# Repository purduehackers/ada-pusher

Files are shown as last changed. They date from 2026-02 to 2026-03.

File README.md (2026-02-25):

# ada-pusher

Companion to [door-opener][door-opener-github] to push the Bechtel ADA button

[door-opener-github]: https://github.com/purduehackers/door-opener

## Links

- [Documentation](./docs/README.md)

## Build

You need to install the [Rust on ESP32][esp32-rs-start] prerequisites. These
commands may be useful:

```
cargo binstall espup
espup install
. ~/export-esp.sh
cargo binstall espflash
cargo binstall ldproxy
```

Create a `.env` file with the following contents:

```
PAIRING_PIN=123456
```

This is the pairing PIN used by `ada-pusher`. Replace with a suitable 6-digit PIN.

Then, build with `cargo build`.

Connect the ESP32 board to your computer and run:

```
espflash flash --monitor target/xtensa-esp32-espidf/debug/ada-pusher
```

[esp32-rs-start]: https://docs.espressif.com/projects/rust/book/getting-started/index.html

## Troubleshooting

### Max path on Windows

On Windows, you may encounter the following error:

```
error: failed to run custom build command for `esp-idf-sys v0.36.1`

Caused by:
  process didn't exit successfully: `C:\Users\user\Projects\ada-pusher\target\debug\build\esp-idf-sys-585097b028c03f00\build-script-build` (exit code: 1)
  --- stderr
  Error: Too long output directory: `\\?\C:\Users\user\Projects\ada-pusher\target\xtensa-esp32-espidf\debug\build\esp-idf-sys-7336b0b778f8f8a0\out`. Shorten your project path down to no more than 10 characters (or use WSL2 and its native Linux filesystem). Note that tricks like Windows `subst` do NOT work!
warning: build failed, waiting for other jobs to finish...
```

This is because you need to explicitly opt in to long file paths on Windows.
Recent versions of Windows enable long paths by default, but you need to let
ESP-IDF know of this. Set the environment variable:

```
$env:ESP_IDF_PATH_ISSUES = "warn"
```

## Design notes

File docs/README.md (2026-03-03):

# Documentation

Welcome to the `ada-pusher` documentation.

## BOM

| Name | URL | Notes |
|---|-----|---|
| ESP32 | The cheapest one you can find | `ESP32-WROOM-32D`, see notes below |
| L298N | [Amazon](https://www.amazon.com/dp/B0C5JCF5RS) | Motor driver/controller for linear actuator |
| LM2596 | [Amazon](https://www.amazon.com/dp/B0DBVYP91F) | Buck converter (15V -> 12V), suitable for motors and high power applications |
| Mini360 | [Amazon](https://www.amazon.com/dp/B08HQDSQZP) | Buck converter (15V -> 5V), suitable for low power applications such as the ESP32 board |
| USB-C PD Trigger Board | [Amazon](https://www.amazon.com/dp/B0CFTXRHLV) | Any trigger board should work, just make sure it supports 15V profile at minimum! |
| Suction cups | [Amazon](https://www.amazon.com/dp/B0DFLZ5FX4) | Other suction cups may need calibration, see notes below |
| 100 nF (0.1 uF) capacitor | | |

### Notes

- For the ESP32, if replacing, try to get one with the RISC-V architecture
  - Implementation `v1` uses `ESP32-WROOM-32D`, which is based on Xtensa, and while it works, there are some annoyances where you have to install a modified toolchain and LLVM compiler from Espressif.
  - Only get Xtensa-based boards if they are significantly cheaper than the RISC-V-based ones.
  - If you are working on `v2`+ and we have switched over to RISC-V-based ESP32 boards, please update this documentation and the main `README.md` of this repository and remove the custom toolchain/LLVM installation mention.
  - WARNING: different ESP32 boards may have different pinouts. If you have replaced the boards, do NOT put them on the pre-existing perfboard without verifying the pinout or you may fry your ESP32 board!
- For suction cups:
  - The Purdue Hackers office will stock replacements, should the existing suction cups on `ada-pusher` wear out. Please ask an organizer/officer if you notice the suction cups need replacing.
  - If the particular suction cups listed in the BOM become unavailable, you may source replacements if the nub portion of the suction cup is around 14.5mm in diameter.
  - If the particular suction cups listed in the BOM become unavailable, **and** the replacements have a different nub dimension:
    - Measure the nub diameter with a caliper.
    - Print out the `suction-cup-hole-calibration.FCStd` file in `../cad/` in this repository. You may need to export the model as a `.step` file.
    - Fit the new suction cup into the calibration and determine the correct hole diameter.
    - Open the `ada-pusher.FCStd` project file in `../cad/` in this repository. Open the spreadsheet.
    - Find the `Suction cup inner nub diameter` entry and change the value next to it. Wait while FreeCAD recalculates the model.
    - Export the new model as a `.step` file.
    - Print out the new model and verify fit.
    - Commit and push the new model to this repository (or make a pull request).

## Circuit

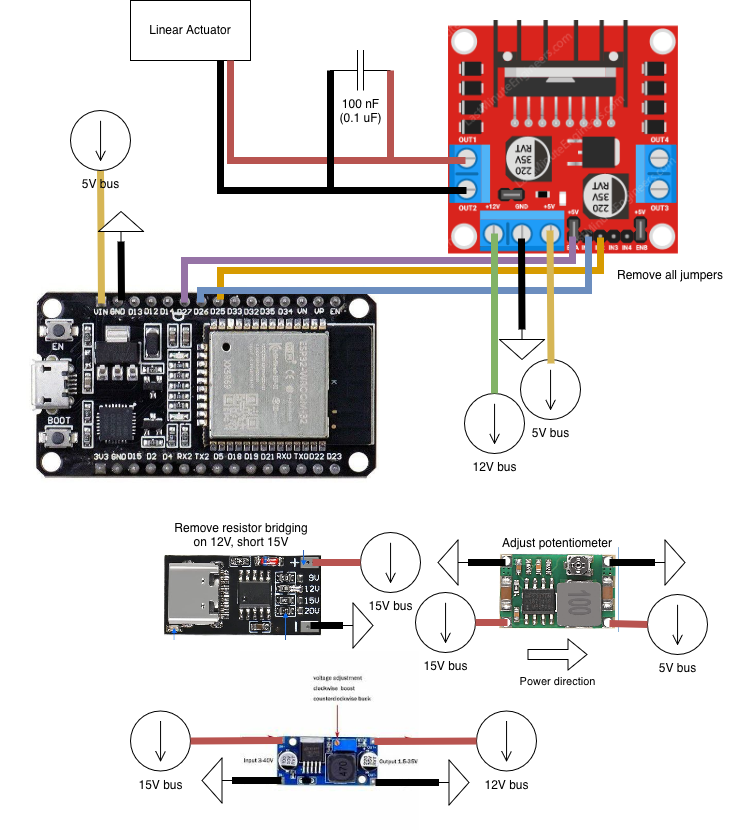
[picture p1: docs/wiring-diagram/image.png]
Circuit diagram


- For the `L298N` driver:
  - Make sure to remove all jumpers. This includes the `ENA` and `ENB` pins, and the voltage regulator jumper (above the 12V and `GND` terminals)! This is because we supply our own 5V, and having it conflict with the 5V voltage regulator of the `L298N` driver board would be problematic!
  - Solder a 100 nF (0.1 uF) capacitor across the output pins (the pins that connect to the linear actuator)
- Adjust the potentiometer on the Mini360 until the output voltage is 5V when input is 15V.
- Adjust the potentiometer on the LM2596 until the output voltage is 12V when input is 15V.
- For the USB-C trigger board:
  - Most USB-C chargers/power adapters do not support the 12V profile, since the USB specification has deemed it optional. Therefore, we get 15V and drop it down to the required voltages, which is probably preferred as the power is more stable overall.
  - The particular board from Amazon comes with a tiny resistor between the 12V profile resistor and ground. You **must** remove this resistor, or else you may get a 9V output.
  - Solder the 15V profile resistor and the ground pad next to it together.
  - Verify 15V output when connected to a capable 15V USB-C PD source with a multimeter.
  - **Warning**: connecting a low-power USB-C PD source or a non-PD USB-C power source will result in the voltage dropping down to the highest voltage that the PD source can supply, which will usually be 5V or 9V. `ada-pusher` will not work with those voltages.
- For the Mini360:
  - The used chip (at least the one from Amazon) is the `MP1482DS`, and the [datasheet can be found here](https://www.monolithicpower.com/en/documentview/productdocument/index/version/2/document_type/Datasheet/lang/en/sku/MP1482/)
    - Funnily enough, the datasheet has a watermark saying the use is discouraged and to move over to the `MP1476`. Perhaps I have received old stock?
  - It may be worth removing the fiddly potentiometer and replacing it with a resistor.
    - The datasheet says Vout is determined by Vout = 0.923 * (R1 + R2) / R2
    - On the Mini360 board, R2 appears to be 8.2k Ohms (from the `822` marking on the resistor)
    - Thus, for Vout = 5V, R1 must be R1 = 5V * 8.2k Ohms / 0.923 - 8.2k Ohms = 36.2k Ohms
    - With testing (theory only goes so far), needed 36.9k Ohms total in order to get stable 5V. Wired 3.9k and 33k Ohm resistors in series:
      Mini360 after resistors are soldered
    - Note: You could also solder between the left pad and the middle pad, not squeeze into the left top and bottom. I did so because I ripped the middle pad off while clipping off the original potentiometer.
    - Wrap with Kapton tape to prevent shorting before assembly.
- For the LM2596:
  - Same thing as Mini360 where we replace the potentiometer with a resistor:
    - According to [the datasheet](https://www.ti.com/lit/ds/symlink/lm2596.pdf), Vout = 1.23 (1 + R2 / R1)
    - On the board, a trimpot ([3296 datasheet](https://www.bourns.com/pdfs/3296.pdf)) provides both R1 and R2.
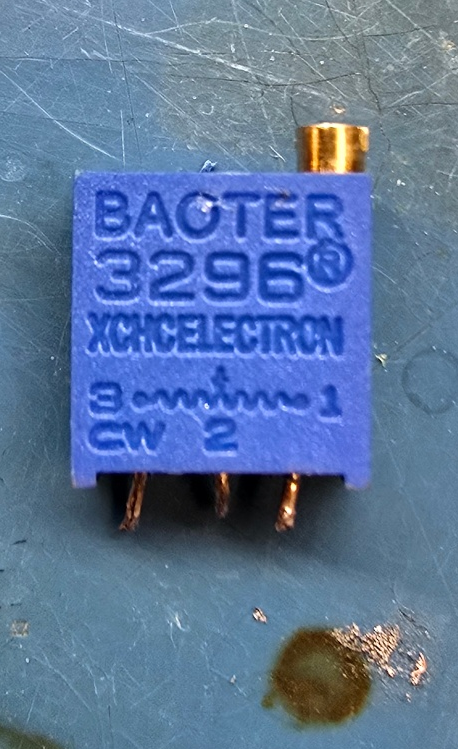
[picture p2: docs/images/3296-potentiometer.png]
3296 potentiometer
      
    - After setting the trimpot to output 12V and desoldering it, the measurements are as follows:
      - Between pins 1 and 2: 2.38k Ohms
      - Between pins 2 and 3: 7.48k Ohms
      - Between pins 1 and 3 (total): 9.8k Ohms
    - Solder resistors such that both legs are in the center pin, and the other legs of the resistors go to each pin hole on either side. In the image, the right resistor is 2.4k Ohms, and the left resistor is 7.5k Ohms.
      LM2596 after resistors are soldered

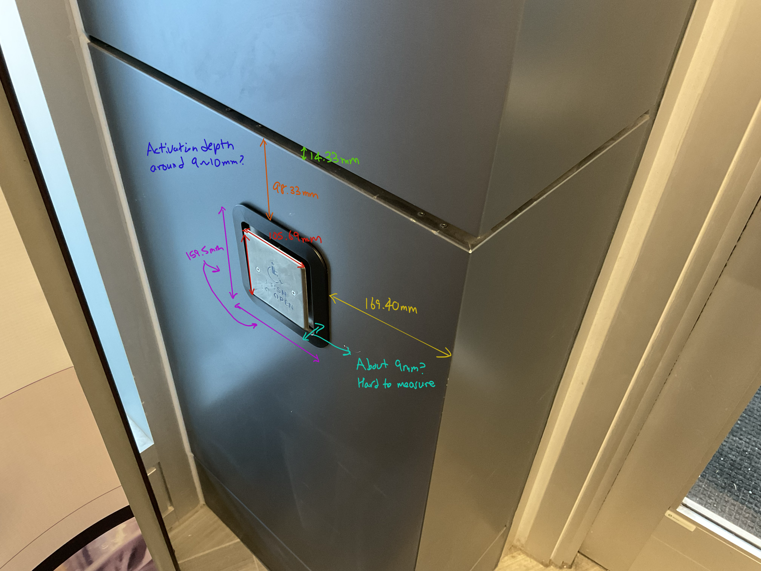
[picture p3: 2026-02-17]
cad/references/reference.png

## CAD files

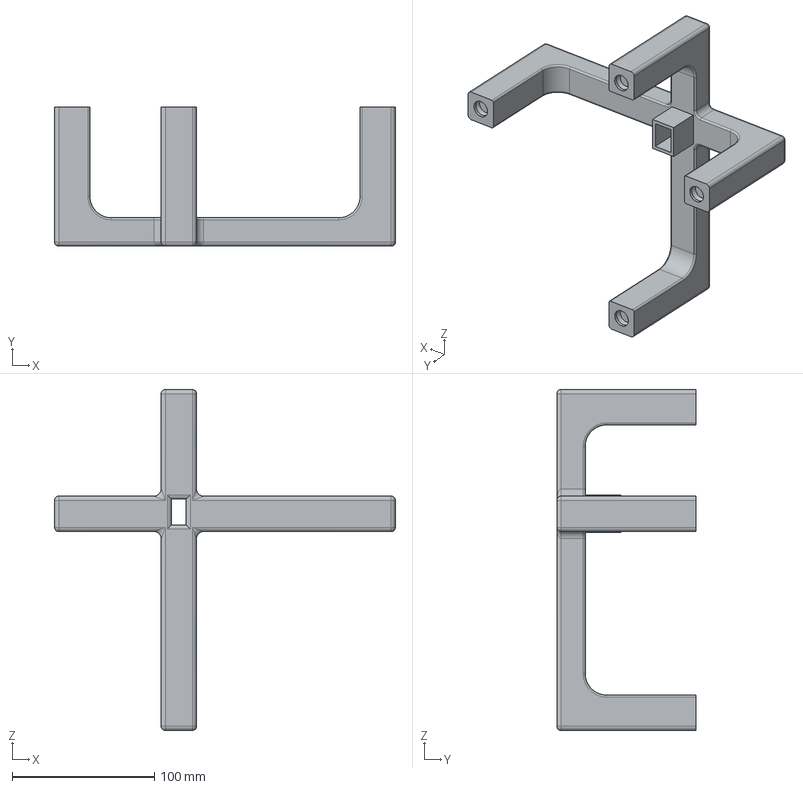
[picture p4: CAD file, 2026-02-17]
cad/parts/ada-pusher_v7.step
240.0 x 98.0 x 240.0 mm

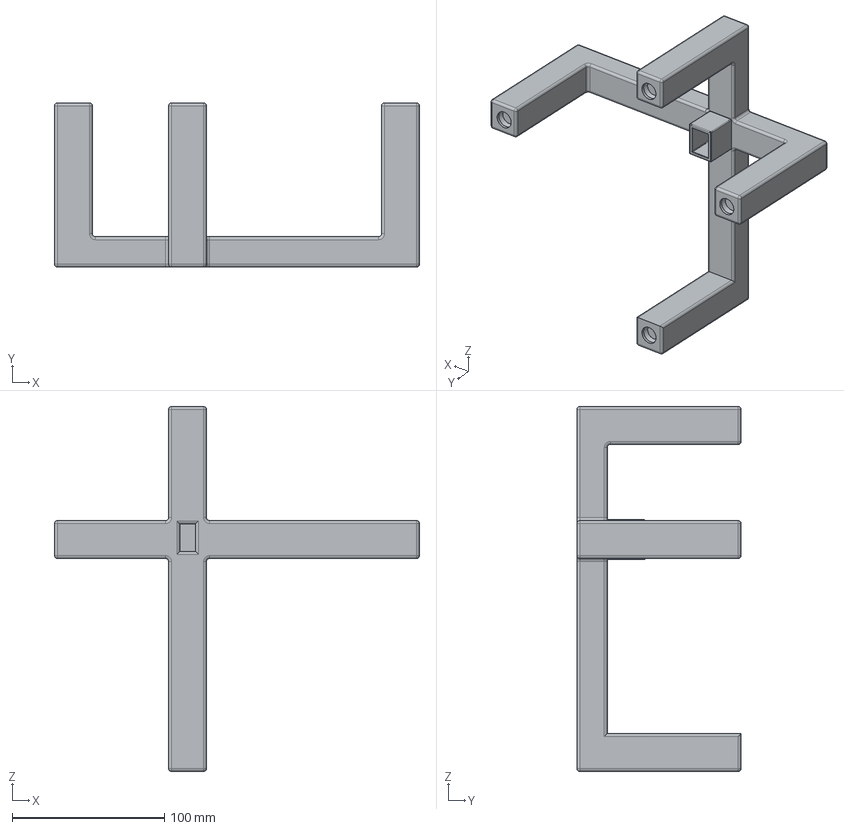
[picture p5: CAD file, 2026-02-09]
cad/ada-pusher-cad_v4.step
240.0 x 108.0 x 240.0 mm

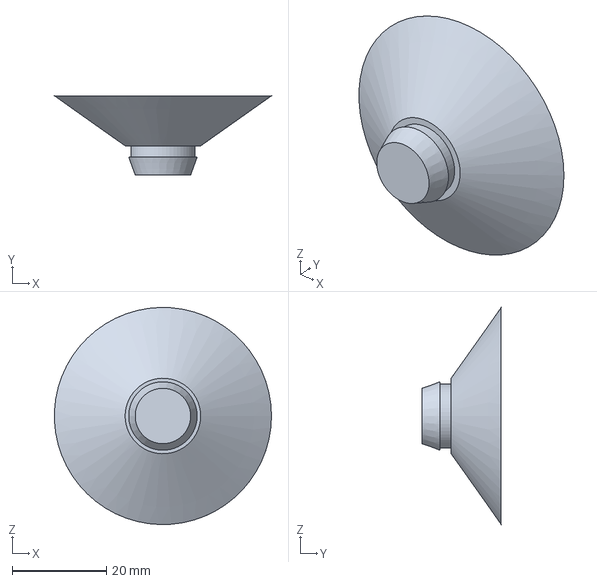
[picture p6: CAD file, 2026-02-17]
cad/parts/suction-cup.FCStd
46.0 x 16.8 x 46.0 mm

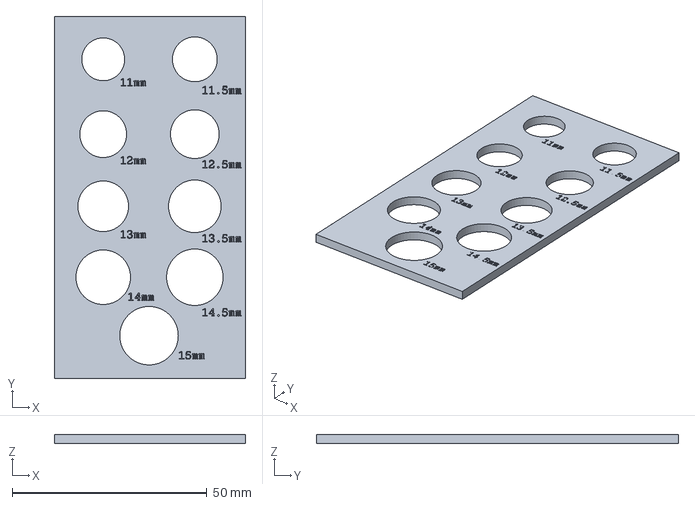
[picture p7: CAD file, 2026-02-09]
cad/suction-cup-hole-calibration.FCStd
49.0 x 92.9 x 2.40 mm

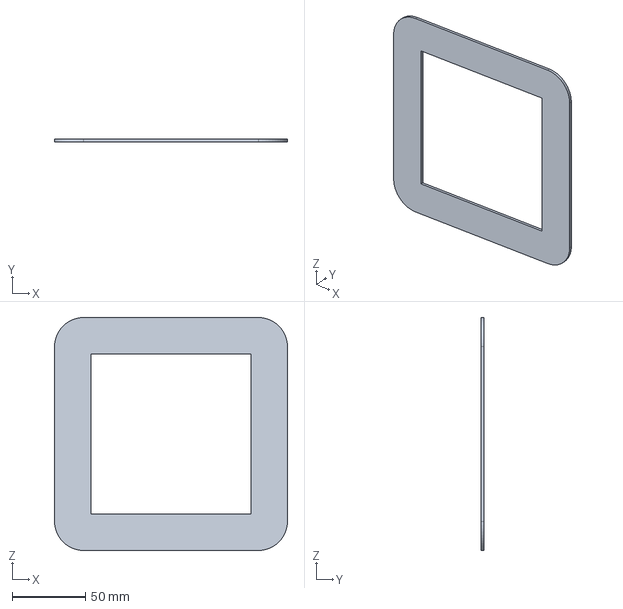
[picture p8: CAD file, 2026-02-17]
cad/parts/button-border.FCStd
159.5 x 2.00 x 159.5 mm

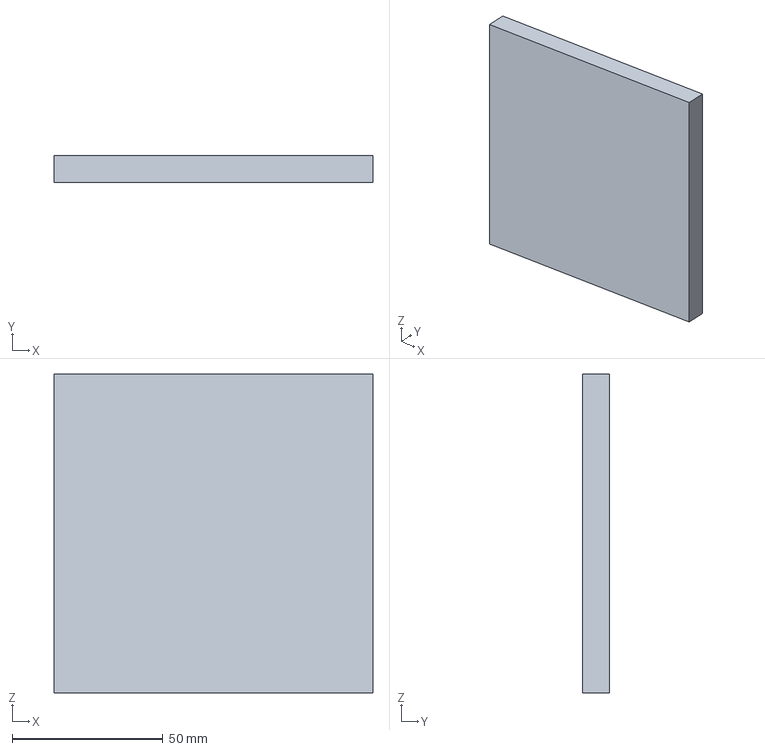
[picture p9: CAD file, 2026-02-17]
cad/parts/button.FCStd
105.7 x 9.00 x 105.7 mm

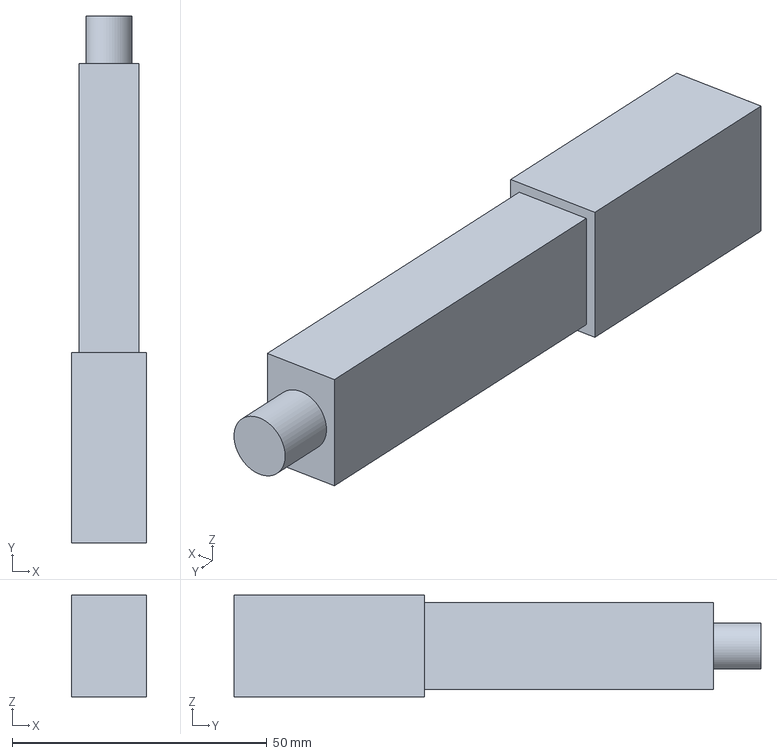
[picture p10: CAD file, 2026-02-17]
cad/parts/linear-actuator.FCStd
14.8 x 103.4 x 20.0 mm

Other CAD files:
cad/assembly.FCStd
cad/parts/ada-pusher.FCStd

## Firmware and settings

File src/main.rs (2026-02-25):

mod l298n;

use std::sync::mpsc;
use std::thread;

use dotenvy_macro::dotenv;
use esp_idf_svc::hal::gpio::{Output, OutputPin, PinDriver};
use esp_idf_svc::hal::prelude::Peripherals;
use esp_idf_svc::sys::EspError;
use esp32_nimble::enums::{AuthReq, SecurityIOCap};
use esp32_nimble::utilities::BleUuid;
use esp32_nimble::{BLEAdvertisementData, BLEDevice, NimbleProperties, uuid128};
use log::{debug, error, info};

use l298n::L298N;

const DOOR_SERVICE_UUID: BleUuid = uuid128!("7e783540-f3ab-431f-adff-566767b8bb30");
const DOOR_COMMAND_CHAR_UUID: BleUuid = uuid128!("7e783540-f3ab-431f-adff-566767b8bb31");
const PAIRING_PIN: &str = dotenv!("PAIRING_PIN");

fn led_blink(led: &mut PinDriver<'_, impl OutputPin, Output>) -> Result<(), EspError> {
    // Rapidly flash the LED five times
    for _ in 0..5 {
        led.set_high()?;
        thread::sleep(std::time::Duration::from_millis(100));
        led.set_low()?;
        thread::sleep(std::time::Duration::from_millis(100));
    }
    Ok(())
}

fn main() -> anyhow::Result<()> {
    // It is necessary to call this function once. Otherwise, some patches to the runtime
    // implemented by esp-idf-sys might not link properly. See https://github.com/esp-rs/esp-idf-template/issues/71
    esp_idf_svc::sys::link_patches();
    // Bind the log crate to the ESP Logging facilities
    esp_idf_svc::log::EspLogger::initialize_default();

    // Initialize BLE and BLE server
    BLEDevice::set_device_name("ada-pusher").expect("Failed to set device name");
    let ble_device = BLEDevice::take();
    let ble_advertising = ble_device.get_advertising();

    // Configure security
    ble_device
        .security()
        .set_auth(AuthReq::all())
        .set_passkey(PAIRING_PIN.parse().expect("Failed to parse pairing pin"))
        .set_io_cap(SecurityIOCap::DisplayOnly)
        .resolve_rpa();

    let server = ble_device.get_server();

    // Configure L298N driver pins
    let peripherals = Peripherals::take()?;
    let mut onboard_led = PinDriver::output(peripherals.pins.gpio2)?;
    let mut l298n = L298N::new(
        PinDriver::output(peripherals.pins.gpio27)?,
        PinDriver::output(peripherals.pins.gpio26)?,
        PinDriver::output(peripherals.pins.gpio25)?,
    );

    server.on_connect(|_server, desc| {
        info!("Client connected: {desc:?}");
    });

    server.on_disconnect(|desc, reason| {
        info!("Client disconnected: {desc:?}, reason: {reason:?}");
    });

    let (tx, rx) = mpsc::channel::<()>();

    thread::spawn(move || {
        while rx.recv().is_ok() {
            match l298n.open_door() {
                Ok(()) => {
                    let _ = led_blink(&mut onboard_led);
                    info!("Sent signal to L298N driver to open door!");
                }
                Err(err) => {
                    error!("Failed to open door, {err:?}");
                }
            }
        }
    });

    let door_service = server.create_service(DOOR_SERVICE_UUID);

    let door_command_char = door_service.lock().create_characteristic(
        DOOR_COMMAND_CHAR_UUID,
        NimbleProperties::READ | NimbleProperties::WRITE | NimbleProperties::WRITE_AUTHEN,
    );

    // Set up callback for when data is written to the characteristic
    door_command_char.lock().on_write(move |args| {
        let data = args.recv_data();
        info!("Received data: {data:?}");

        if data == b"open" {
            match tx.send(()) {
                Ok(()) => {
                    debug!("Sent signal to door opener thread");
                }
                Err(err) => {
                    error!("Failed to notify door opener thread, {err:?}");
                }
            }
        }
    });

    // Configure advertising
    let mut advertising_data = BLEAdvertisementData::new();
    advertising_data.name("ada-pusher");
    advertising_data.add_service_uuid(DOOR_SERVICE_UUID);
    ble_advertising.lock().set_data(&mut advertising_data).ok();

    // Start advertising
    ble_advertising.lock().start()?;
    info!("BLE advertising started, waiting for connections...");
    info!("Currently bonded: {:?}", ble_device.bonded_addresses());
    // Run loop
    loop {
        std::thread::sleep(std::time::Duration::from_secs(1));
    }
}

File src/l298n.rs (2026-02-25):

use std::thread;
use std::time::Duration;

use esp_idf_svc::hal::gpio::{Output, OutputPin, PinDriver};
use esp_idf_svc::sys::EspError;

pub struct L298N<ENA, IN1, IN2>
where
    ENA: OutputPin,
    IN1: OutputPin,
    IN2: OutputPin,
{
    ena: PinDriver<'static, ENA, Output>,
    in1: PinDriver<'static, IN1, Output>,
    in2: PinDriver<'static, IN2, Output>,
}

impl<ENA, IN1, IN2> L298N<ENA, IN1, IN2>
where
    ENA: OutputPin,
    IN1: OutputPin,
    IN2: OutputPin,
{
    pub fn new(
        ena: PinDriver<'static, ENA, Output>,
        in1: PinDriver<'static, IN1, Output>,
        in2: PinDriver<'static, IN2, Output>,
    ) -> Self {
        Self { ena, in1, in2 }
    }

    pub fn open_door(&mut self) -> Result<(), EspError> {
        self.forward()?;
        self.enable_motor()?;
        thread::sleep(Duration::from_millis(2000));
        self.backward()?;
        thread::sleep(Duration::from_millis(2000));
        self.disable_motor()?;
        Ok(())
    }

    fn enable_motor(&mut self) -> Result<(), EspError> {
        self.ena.set_high()?;
        Ok(())
    }

    fn disable_motor(&mut self) -> Result<(), EspError> {
        self.ena.set_low()?;
        Ok(())
    }

    fn forward(&mut self) -> Result<(), EspError> {
        self.in1.set_high()?;
        self.in2.set_low()?;
        Ok(())
    }

    fn backward(&mut self) -> Result<(), EspError> {
        self.in1.set_low()?;
        self.in2.set_high()?;
        Ok(())
    }
}

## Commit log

2026-01-22 Initial test Arduino sketch
2026-02-03 feat: add initial CAD and .gitignore
2026-02-03 Add linear actuator part specs from AliExpress
2026-02-03 fix: add some linear actuator dimensions
2026-02-04 fix(cad): add linear actuator model and assembly view
2026-02-04 fix(cad): initial ada-pusher design, suction cup modelling
2026-02-04 fix(cad): adjust ada-pusher spacing, add pocket for linact
2026-02-04 fix(cad): cuts with suction cups
2026-02-04 feat(cad): first ada-pusher hw design done
    [final-ada-pusher-cuts.stl]
2026-02-04 fix(cad): export step as well
    [ada-pusher-final-ada-pusher-cuts.step]
2026-02-08 build: add esp32-nimble
2026-02-08 feat(cad): add initial suction cup hole calibration project file
    [suction-cup-hole-calibration.FCStd]
2026-02-09 fix: finish suction cup calibration model
    [suction-cup-hole-calibration.FCStd, suction-cup-hole-calibration.step]
2026-02-09 feat: add esp32-nimble code
2026-02-09 fix(cad): tweak ada-pusher legs
    Make them shorter to account for the suction cups
    [ada-pusher-cad_v2.step, ada-pusher-final-ada-pusher-cuts.step, final-ada-pusher-cuts.stl]
2026-02-09 fix(cad): preliminary v3 model
    Changes:
    - Moved back suction cups to account for shorter leg length
    - Tweaked suction inner nub diameter by 3 mm (preliminary, test needed)
    - Increased suction nub diameter by .1 mm
    [ada-pusher-cad_v3.step]
2026-02-09 fix(cad): increase suction cup inner nub diameter to 13.5mm
2026-02-09 fix(cad): add more fillets
    Should help with structural integrity
2026-02-09 fix(cad): export v4 model and delete rest
    [ada-pusher-cad_v2.step, ada-pusher-cad_v3.step, ada-pusher-cad_v4.step]
2026-02-09 fix(cad): shorten legs of ada-pusher by 6.5mm
    We already shortened legs by 2mm back in v3 (or v2?), but that's not
    enough because the suction cup's depth is 8.5mm. Shorten it by an
    additional 6.5mm to get the linear actuator to sit perfectly flush with
    the ADA button.
    Fingers crossed
    [ada-pusher-cad_v5.step, suction-cup-hole-calibration.step]
2026-02-09 fix(cad): actually move suction cups after shortening legs
    Oops
    [ada-pusher-cad_v5.step, ada-pusher-cad_v6.step]
2026-02-11 fix: NVS key name too long
    Max is 15 characters
    [main.rs]
2026-02-11 fix: don't print MAC ID on fetch from NVS
    [main.rs]
2026-02-11 fix: implement actual linear actuator driving code
    [main.rs]
2026-02-11 refactor: bring out l298n driver code to separate file
2026-02-11 fix: add security configuration and pairing
    TODO: dynamically load in PIN during compile
    [main.rs]
2026-02-11 fix: remove example Arduino sketch
2026-02-11 fix: define pairing pin in env var
    [main.rs]
2026-02-11 docs: add removal request when RISC-V switch
2026-02-12 docs: update LM2596 resistor values and soldering instructions
2026-02-12 docs: update Mini360 resistor values
2026-02-12 docs: add note about L298N voltage regulator jumper
2026-02-14 fix: use uuid128s again
    [main.rs]
2026-02-14 docs: update with capacitor and jumper removal
2026-02-14 fix: use dotenvy_macro to load in compile-time env var
    [main.rs]
2026-02-14 fix: add more debug messages
    [main.rs]
2026-02-14 fix: blink LED on door open
    Also refactored L298N to accept any generic output pin
    [l298n.rs, main.rs]
2026-02-14 fix: set device name to ada-pusher
    This was why it was showing as nimble sometimes
    [main.rs]
2026-02-14 fix: don't keep LED on after open
    [main.rs]
2026-02-17 refactor(cad): bring out suction cup to part
    [ada-pusher.FCStd, suction-cup.FCStd]
2026-02-17 fix(cad): union suction cups before cut
    Makes for a cleaner tree
    [ada-pusher.FCStd]
2026-02-17 fix(cad): remove unused suction cup variables
    [ada-pusher.FCStd]
2026-02-17 refactor(cad): bring out linear actuator part
    [ada-pusher.FCStd, linear-actuator.FCStd]
2026-02-17 refactor(cad): bring out button
    [ada-pusher.FCStd, button.FCStd]
2026-02-17 refactor(cad): bring out button border and all variables
    [ada-pusher.FCStd, button-border.FCStd]
2026-02-17 fix(cad): bring out ada-pusher to part and rename assembly
    [ada-pusher.FCStd, assembly.FCStd, suction-cup.FCStd]
2026-02-17 fix(cad): shorten legs and align suction cups
    - Shorten legs from 81.50 mm to 78.mm (3.5 mm shorter)
    - suction cups were off by 0.1 mm, align at 8.8 mm
    [ada-pusher.FCStd]
2026-02-17 fix(cad): add fillets to ada-pusher model
    [ada-pusher.FCStd]
2026-02-17 fix(cad): remove old print file
    [ada-pusher-cad_v6.step]
2026-02-17 fix(cad): add references folder
2026-02-17 fix(cad): export ada-pusher v7
    [ada-pusher_v7.step]
2026-02-25 fix: cargo clippy suggestions
    [l298n.rs, main.rs]
2026-03-03 docs: add warning about replacing ESP32 board
